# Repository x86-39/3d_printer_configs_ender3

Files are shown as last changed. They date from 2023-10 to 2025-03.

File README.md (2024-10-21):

# creality_ender3_sprite_pro_configs
Configurations for my Ender 3 with the Creality Sprite Pro extruder

It was bought as a stock Ender 3, and I've added the following upgrades:
- Creality Sprite Pro extruder
- BLTouch
- Dual Z-axis
- Raspberry Pi 4 with Moonsail
- Klipper firmware
- USB webcam

## Generate PrusaSlicer print configs

I still include these in the repo bcs having an easy history of changes is nice. But you can generate them yourself if you want to change the settings.

The print configs in the PrusaSlicer folder are generated from the `generate.yml` playbook. Why Ansible? Because it's my golden hammer, next question. It takes a base config in `roles/generate_print/templates/` and generates a config for each possible permutation of variables such as speed, toughness and precision. You can then use `./copy-to-prusaslicer.sh` to copy the generated configs to your PrusaSlicer config folder.
Is this the best way to do it? No definitely not, but it works for me and I'm stubborn as fuck and will use Ansible when I can.
```
ansible-playbook generate.yml
```

Also, the playbook is a mess. I definitely could've procedurally generated it, but I was tired and just wanted it to work and don't think anyone is gonna download these anyway!

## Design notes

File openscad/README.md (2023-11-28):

# Creality Sprite Pro 40mm Fan Duct
I broke my Sprite Pro hot end cooling fan, so I made a model so it fits a 40mm fan I had instead of a 30mm fan. I don't use this anymore since I have a new 30mm fan and board now, but it worked well for a while. Here's the model if anyone else needs it. I used heat inserts to fit the screws for the board, fan and BLTouch.

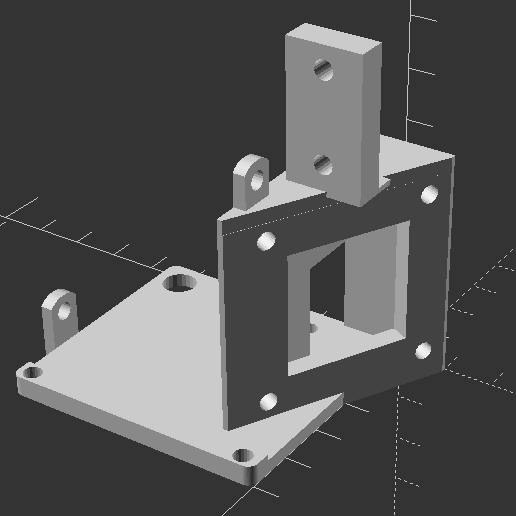
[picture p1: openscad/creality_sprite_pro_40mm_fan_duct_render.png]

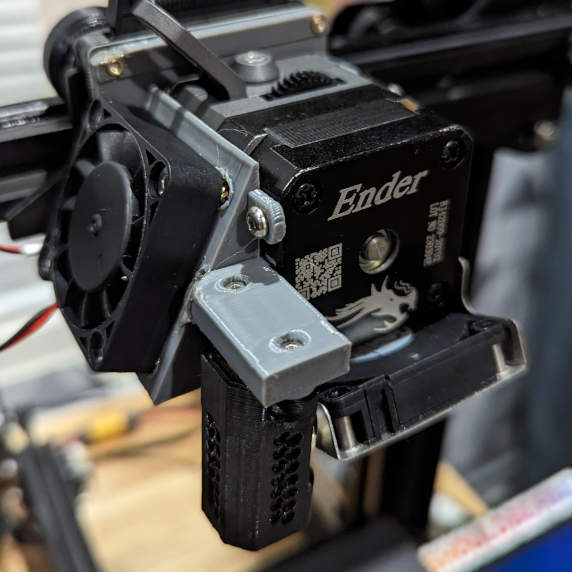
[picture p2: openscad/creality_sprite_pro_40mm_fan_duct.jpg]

<br clear="left"/>

You can download the model at the [Releases tab](https://github.com/diademiemi/3d_printer_configs_ender3/releases/tag/2023-10-28)

# Creality Sprite Pro BLTouch Raiser
The BLTouch I use was too low, it kept bumping into prints and especially the bed clips, so I made a model to raise it by 3.6 millimeters. This will offset the Z axis by 3.5 millimeters, X axis by 13.5 millimeters and Y axis by 0 millimeters.

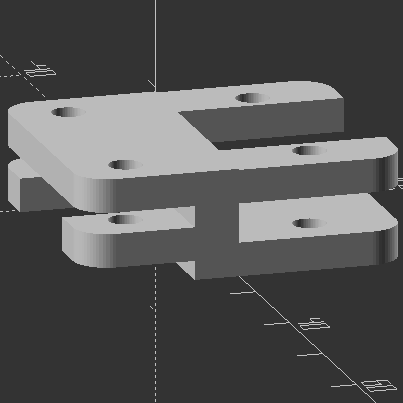
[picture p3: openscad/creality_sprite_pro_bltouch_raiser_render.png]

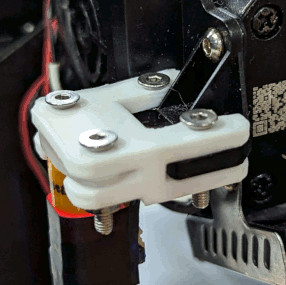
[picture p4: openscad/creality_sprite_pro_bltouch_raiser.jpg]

<br clear="left"/>

You can download the model at the [Releases tab](https://github.com/diademiemi/3d_printer_configs_ender3/releases/tag/2023-11-26)

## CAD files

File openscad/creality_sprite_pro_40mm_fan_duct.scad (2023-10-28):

/*
I broke my Sprite Pro hot end cooling fan, so I made a model so it fits a 40mm fan instead of a 30mm fan. I don't use this anymore since I have a new 30mm fan and board now, but it worked well for a while. Here's the model if anyone else needs it
*/
// github.com/diademiemi/openscad_common
include <openscad_common/rounded_figures.scad>

union() {

    // MAIN BODY

    difference() {
        union() {
            // Main body
            rounded_cube([54, 50.5, 2.8], 2, flat_minus_z = true, flat_plus_z = true);

            // Side screw plate
            difference() {
                // Plate
                translate([54, 31, 0]) {
                    rounded_cube([2.5, 7.1, 13], 4, flat_minus_z = true, flat_minus_x = true, flat_plus_x = true);
                }

                // Hole
                translate([54, 34.55, 9.5]) rotate([0,90,0]) {
                    cylinder(r = 1.8, h = 3, $fn=24);
                    
                }

            }

            // Top notch
            translate([0, 45.5, 2.8]) {
                rounded_cube([54, 5, 1.3], 2, flat_minus_z = true, flat_plus_z = true, flat_minus_y = true);
            }
        }

        // Top notch heat inserts, TOO FAR TO THE CENTER
        translate([0, 48, 0]) {
            translate([3.5, 0, 0]) {
                cylinder(r = 1.9, h = 5, $fn=24);
            }
            translate([51, 0, 0]) {
                cylinder(r = 1.9, h = 5, $fn=24);
            }
        }

        translate([11.25, 40 , 0]) {
            rounded_cube([30, 9.5, 1.8], 2);
        }

        // Square cutout
        translate([25, 0, 0]) {
            rounded_cube([12, 8, 3], 3, flat_minus_z = true, flat_plus_z = true, flat_minus_y = true);
        }

        // Screw
        translate([17.2, 5.6, 0]) {
            cylinder(r = 1.8, h = 3, $fn=24);
        }

        // Screw passthrough
        translate([48.5, 5.5, 0]) {
            cylinder(r = 3.5, h = 3, $fn=24);
        }

        // Cutout for heater pins
        translate([44, 10, 0]) {
            rounded_cube([10, 5, 2], 3, flat_minus_z = true, flat_plus_z = true, flat_plus_x = true);
        }
    }

    // FAN DUCT
    
    cube([3,3,2.8]); // Make corner flat
    // Don't cross into next part
    intersection() {
        translate([-10,0,0]) cube([22,42,45.6]);
        union() {
            translate([-9.5, 2, 2.8]) rotate([0,0,-27]) {
                difference() {
                    // Fan mount
                    translate([0,-5,0]) cube([4, 55, 40]);  // Actual size is not 50, but I use 55 so it fills in the corners of the intersection
                    // Fan hole
                    translate([0, 7.5, 7.5]) cube([4, 25, 25]);


                    // Screw holes
                    rotate([0,-90,0]) translate([3.4,3.4,-4]) cylinder(r=1.8, h=5, $fn=24);
                    rotate([0,-90,0]) translate([36.6,3.4,-4]) cylinder(r=1.8, h=5, $fn=24);
                    rotate([0,-90,0]) translate([3.4,36.6,-4]) cylinder(r=1.8, h=5, $fn=24);
                    rotate([0,-90,0]) translate([36.6,36.6,-4]) cylinder(r=1.8, h=5, $fn=24);

                }

            }
            // Bottom plate
            hull() {
                translate([-10, 0, 0]) cube([22, 1, 2.8]);
                translate([11, 0, 0]) rotate([0, 0, 0]) rounded_cube([2, 42, 2.8], 2, flat_minus_y = true, flat_plus_y = true);
            }
            // Top plate
            hull() {
                translate([-10, 0, 42.8]) cube([22, 1, 2.8]);
                translate([11, 0, 42.8]) rotate([0, 0, 0]) rounded_cube([2, 42, 2.8], 2, flat_minus_y = true, flat_plus_y = true);
            }
            // Front plate
            translate([-10, 0, 0]) cube([22, 1, 42.8]);

            // Closing plate
            translate([11, 0, 0]) difference() {
                cube([1, 40, 42.8]);
                // Vent hole
                translate([0, 0, 2.8]) cube([1, 15, 20]);
            }

        }

    }

    // BLTouch mount
    translate([-5, 18, 45.6]) difference(){
    
        cube([15, 6, 27]);

        translate([7.5,6,5]) rotate([90,0,0]) cylinder(r=1.9, h=6, $fn=24);
        translate([7.5,6,22.5]) rotate([90,0,0]) cylinder(r=1.9, h=6, $fn=24);


    }
    translate([-5,14,44.6]) cube([10,10,1]);

    translate([9.5, 30, 45.6]) difference() {
            // Side screw plate
            // Plate
            rounded_cube([2.5, 7.1, 8], 4, flat_minus_z = true, flat_minus_x = true, flat_plus_x = true);

            // Hole
            translate([0, 3.5, 4.25]) rotate([0,90,0]) {
                cylinder(r = 1.8, h = 3, $fn=24);
            }

        }

    /*
    The fan duct should close at the bottom. Have a panel at the side facing the extruder.
    It should only open at the panel at the bottom left for the size of the betal block.
    This is where the air exists. The duct can be moved 1cm to the right
    */


}

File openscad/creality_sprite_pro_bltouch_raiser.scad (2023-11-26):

include <openscad_common/rounded_figures.scad>

bltouch_size = [25, 10, 3];
extruder_size = [25, 15, 3];

screw_hole_radius = 1.5;


extra_height = 3.6;

wall_thickness = 4;
sprite_pro_extruder_thickness = 3.5;
wall_height = bltouch_size[2]*2 + extra_height;

bltouch_mount_thickness = 1.9;

module bltouch_mount(bltouch_size = bltouch_size, screw_hole_radius = screw_hole_radius) {
    difference() {
        rounded_cube(bltouch_size, 3, flat_plus_z=true, flat_minus_z=true, flat_minus_y=true);
        translate([2.5 + screw_hole_radius, bltouch_size[1] / 2, 0]) {
            translate([0, 0, bltouch_size[2]/2]) cylinder(r=1.5, h=bltouch_size[2]*2, center=true, $fn=64);
        }
        translate([bltouch_size[0] - 2.5 - screw_hole_radius, bltouch_size[1] / 2, 0]) {
            translate([0, 0, bltouch_size[2]/2]) cylinder(r=1.5, h=bltouch_size[2]*2, center=true, $fn=64);
        }
    }
}


module extruder_mount(extruder_size = extruder_size, screw_hole_radius = screw_hole_radius) {
    difference() {
        rounded_cube(extruder_size, 3, flat_plus_z=true, flat_minus_z=true, flat_minus_y=true);
        translate([2.5 + screw_hole_radius, extruder_size[1] / 2, 0]) {
            translate([0, 0, extruder_size[2]/2]) cylinder(r=1.5, h=extruder_size[2]*2, center=true, $fn=64);
        }
        translate([extruder_size[0] - 2.5 - screw_hole_radius, extruder_size[1] / 2, 0]) {
            translate([0, 0, extruder_size[2]/2]) cylinder(r=1.5, h=extruder_size[2]*2, center=true, $fn=64);
        }
    }
}


// Extruder Mount

extruder_mount();

translate([0, 0, bltouch_size[2] + sprite_pro_extruder_thickness]) {
    difference() {
        extruder_mount();
        translate([extruder_size[0]/4, 0, 0]) cube([extruder_size[0]/2, extruder_size[1], extruder_size[2]]);
    }
}

// Wall

translate([0, -wall_thickness, 0]) {
    cube([bltouch_size[0], wall_thickness, wall_height]);
}

// BlTouch Mount

translate([0, -(wall_thickness), (bltouch_size[2]*2) + extra_height]) {
    rotate([180, 0, 0]) bltouch_mount();
}

translate([0, -(wall_thickness), (bltouch_size[2]) + extra_height - bltouch_mount_thickness]) {
    rotate([180, 0, 0]) difference() {
        bltouch_mount();
        translate([bltouch_size[0]/4, 0, 0]) cube([bltouch_size[0]/2, bltouch_size[1], bltouch_size[2]]);
    }
}

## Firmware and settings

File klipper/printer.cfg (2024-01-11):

# This file contains pin mappings for the stock 2020 Creality Ender 3
# V2. To use this config, during "make menuconfig" select the
# STM32F103 with a "28KiB bootloader" and serial (on USART1 PA10/PA9)
# communication.

# If you prefer a direct serial connection, in "make menuconfig"
# select "Enable extra low-level configuration options" and select
# serial (on USART3 PB11/PB10), which is broken out on the 10 pin IDC
# cable used for the LCD module as follows:
# 3: Tx, 4: Rx, 9: GND, 10: VCC

# Flash this firmware by copying "out/klipper.bin" to a SD card and
# turning on the printer with the card inserted. The firmware
# filename must end in ".bin" and must not match the last filename
# that was flashed.

# See docs/Config_Reference.md for a description of parameters.

[include mainsail.cfg]

[include timelapse.cfg]

[stepper_x]
step_pin: PB9
dir_pin: PC2
enable_pin: !PC3
microsteps: 16
rotation_distance: 40
endstop_pin: ^PA5
position_endstop: -10
position_min: -15
position_max: 210
homing_speed: 75

[stepper_y]
step_pin: PB7
dir_pin: PB8
enable_pin: !PC3
microsteps: 16
rotation_distance: 40
endstop_pin: ^PA6
position_endstop: -10
position_min: -15
position_max: 220
homing_speed: 75

[stepper_z]
step_pin: PB5
dir_pin: !PB6
enable_pin: !PC3
microsteps: 16
rotation_distance: 8
endstop_pin: probe:z_virtual_endstop
#position_endstop: 0.0
position_min: -5
position_max: 250

[extruder]
max_extrude_only_distance: 100.0
step_pin: PB3
dir_pin: PB4
enable_pin: !PC3
microsteps: 16
#rotation_distance: 7.531  # Stock
rotation_distance: 7.55  # Calibrated
nozzle_diameter: 0.400
filament_diameter: 1.750
heater_pin: PA1
sensor_type: EPCOS 100K B57560G104F
sensor_pin: PC5
control: pid
# tuned for stock hardware with 200 degree Celsius target
pid_Kp: 24.488
pid_Ki: 1.020
pid_Kd: 146.928
min_temp: 0
max_temp: 270

[verify_heater extruder]
heating_gain: 1
hysteresis: 7
check_gain_time: 30
max_error: 150

[heater_bed]
heater_pin: PA2
sensor_type: EPCOS 100K B57560G104F
sensor_pin: PC4
control: pid
# tuned for stock hardware with 50 degree Celsius target
pid_Kp: 54.027
pid_Ki: 0.770
pid_Kd: 948.182
min_temp: 0
max_temp: 130

[fan]
pin: PA0
max_power: 1.0
cycle_time: 0.010

[mcu]
serial: /dev/serial/by-id/usb-1a86_USB_Serial-if00-port0
restart_method: command

[printer]
kinematics: cartesian
max_velocity: 300
max_accel: 3000
max_z_velocity: 5
max_z_accel: 100

[bltouch]
sensor_pin: ^PROBE_IN
control_pin: PROBE_OUT
x_offset: -41
y_offset: -43
#z_offset: 4.950
z_offset: 1.650
probe_with_touch_mode: true
stow_on_each_sample: true

[bed_mesh]
speed: 250
mesh_min: 5, 5
mesh_max: 165, 165
probe_count: 5,5
algorithm: bicubic
horizontal_move_z: 7

[safe_z_home]
home_xy_position: 137.5,127.5
speed: 75
z_hop: 15
z_hop_speed: 5

######################################################################
# 128x64 Full Graphic Creality CR10 / ENDER 3 stockdisplay
######################################################################

# This section is used for a Creality "12864" display with a single
# ribbon cable between the display's EXP3 plug and the
# micro-controller board's EXP1 connector.

[display]
lcd_type: st7920
cs_pin: EXP1_7
sclk_pin: EXP1_6
sid_pin: EXP1_8
encoder_pins: ^EXP1_5, ^EXP1_3
click_pin: ^!EXP1_2

[display_status]

[output_pin beeper]
pin: EXP1_1
value: 0
shutdown_value: 0
pwm: True
cycle_time: 0.0005 ; Default beeper tone in kHz. 1 / 0.0005 = 2000Hz (2kHz)

[board_pins]
aliases:
  EXP1_1=PC6,EXP1_3=PB10,EXP1_5=PB14,EXP1_7=PB12,EXP1_9=<GND>,
  EXP1_2=PB2,EXP1_4=PB11,EXP1_6=PB13,EXP1_8=PB15,EXP1_10=<5V>,
  PROBE_IN=PB1,PROBE_OUT=PB0,FIL_RUNOUT=PC6


[gcode_macro BEEP]
gcode:
    # Parameters
    {% set i = params.I|default(3)|int %}           ; Iterations (number of times to beep).
    {% set dur = params.DUR|default(500)|int %}     ; Duration/wait of each beep in ms. Default 100ms.
    {% set freq = params.FREQ|default(2500)|int %}  ; Frequency in Hz. Default 2kHz.

    {% for iteration in range(i|int) %}
        SET_PIN PIN=beeper VALUE=0.8 CYCLE_TIME={ 1.0/freq if freq > 0 else 1 }
        G4 P{dur}
        SET_PIN PIN=beeper VALUE=0
        G4 P{dur}
    {% endfor %}

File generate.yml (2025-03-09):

- name: Generate PrusaSlicer configs
  hosts: localhost
  vars:
    speed_safe:
      perimeter_speed: 60
      small_perimeter_speed: 50
      external_perimeter_speed: 60
      infill_speed: 75
      solid_infill_speed: 80
      top_solid_infill_speed: 75
      support_material_speed: 50
      support_material_interface_speed: 50
      bridge_speed: 30
      gap_fill_speed: 80
      ironing_speed: 50

      overhang_speed_0: 8
      overhang_speed_1: 15
      overhang_speed_2: 25
      overhang_speed_3: 40

      travel_speed: 80
      travel_speed_z: 5

      first_layer_speed: 20

      external_perimeter_acceleration: 500
      perimeter_acceleration: 600
      top_solid_infill_acceleration: 700
      solid_infill_acceleration: 800
      infill_acceleration: 700
      bridge_acceleration: 600
      first_layer_acceleration: 100
      travel_acceleration: 700
      default_acceleration: 700

      max_print_speed: 80
      max_volumetric_speed: 10
    speed_fast:
      perimeter_speed: 175
      small_perimeter_speed: 140
      external_perimeter_speed: 140
      infill_speed: 200
      solid_infill_speed: 150
      top_solid_infill_speed: 150
      support_material_speed: 75
      support_material_interface_speed: 80
      bridge_speed: 45
      gap_fill_speed: 120
      ironing_speed: 70

      overhang_speed_0: 10
      overhang_speed_1: 25
      overhang_speed_2: 40
      overhang_speed_3: 60

      travel_speed: 200
      travel_speed_z: 5

      first_layer_speed: 20

      external_perimeter_acceleration: 700
      perimeter_acceleration: 900
      top_solid_infill_acceleration: 700
      solid_infill_acceleration: 900
      infill_acceleration: 900
      bridge_acceleration: 800
      first_layer_acceleration: 500
      travel_acceleration: 1400
      default_acceleration: 1400

      max_print_speed: 180
      max_volumetric_speed: 15
    toughness_prototype:
      perimeters: 2
      bottom_solid_layers: 1
      top_solid_layers: 1
      fill_density: 7
      fill_pattern: rectilinear
    toughness_standard:
      perimeters: 3
      bottom_solid_layers: 3
      top_solid_layers: 3
      fill_density: 15
      fill_pattern: honeycomb
    toughness_thick_walls:
      perimeters: 5
      bottom_solid_layers: 4
      top_solid_layers: 4
      fill_density: 15
      fill_pattern: honeycomb
    toughness_strong:
      perimeters: 4
      bottom_solid_layers: 3
      top_solid_layers: 3
      fill_density: 30
      fill_pattern: honeycomb
    toughness_solid:
      perimeters: 5
      bottom_solid_layers: 5
      top_solid_layers: 5
      fill_density: 70
      fill_pattern: honeycomb
    precision_fine:
      layer_height: 0.12
      first_layer_height: 0.2
    precision_detailed:
      layer_height: 0.2
      first_layer_height: 0.25
    precision_standard:
      layer_height: 0.25
      first_layer_height: 0.28
    precision_chunky:
      layer_height: 0.32
      first_layer_height: 0.32

  roles:
  # Fine: 0
  # Detailed: 1
  # Standard: 2
  # Chunky: 3

  # Prototype: 0
  # Standard: 1
  # Thick walls: 2
  # Strong: 3
  # Solid: 4

  # Safe: 0
  # Fast: 1

  # Fine - Prototype
    - { role: generate_print, filename: "Creality Ender 3 Custom - [000] P:Fine, T:Prototype, S:Safe",
        precision: "{{ precision_fine }}", toughness: "{{ toughness_prototype }}", speed: "{{ speed_safe }}" }
    - { role: generate_print, filename: "Creality Ender 3 Custom - [001] P:Fine, T:Prototype, S:Fast",
        precision: "{{ precision_fine }}", toughness: "{{ toughness_prototype }}", speed: "{{ speed_fast }}" }

  # Fine - Standard
    - { role: generate_print, filename: "Creality Ender 3 Custom - [010] P:Fine, T:Standard, S:Safe",
        precision: "{{ precision_fine }}", toughness: "{{ toughness_standard }}", speed: "{{ speed_safe }}" }
    - { role: generate_print, filename: "Creality Ender 3 Custom - [011] P:Fine, T:Standard, S:Fast",
        precision: "{{ precision_fine }}", toughness: "{{ toughness_standard }}", speed: "{{ speed_fast }}" }

  # Fine - Thick walls
    - { role: generate_print, filename: "Creality Ender 3 Custom - [020] P:Fine, T:Thick walls, S:Safe",
        precision: "{{ precision_fine }}", toughness: "{{ toughness_thick_walls }}", speed: "{{ speed_safe }}" }
    - { role: generate_print, filename: "Creality Ender 3 Custom - [021] P:Fine, T:Thick walls, S:Fast",
        precision: "{{ precision_fine }}", toughness: "{{ toughness_thick_walls }}", speed: "{{ speed_fast }}" }

  # Fine - Strong
    - { role: generate_print, filename: "Creality Ender 3 Custom - [030] P:Fine, T:Strong, S:Safe",
        precision: "{{ precision_fine }}", toughness: "{{ toughness_strong }}", speed: "{{ speed_safe }}" }
    - { role: generate_print, filename: "Creality Ender 3 Custom - [031] P:Fine, T:Strong, S:Fast",
        precision: "{{ precision_fine }}", toughness: "{{ toughness_strong }}", speed: "{{ speed_fast }}" }
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

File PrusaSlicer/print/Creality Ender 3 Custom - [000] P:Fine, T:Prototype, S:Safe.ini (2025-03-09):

arc_fitting = disabled
avoid_crossing_curled_overhangs = 0
avoid_crossing_perimeters = 0
avoid_crossing_perimeters_max_detour = 0
bottom_fill_pattern = monotonic
bottom_solid_layers = 1
bottom_solid_min_thickness = 0
bridge_acceleration = 600
bridge_angle = 0
bridge_flow_ratio = 0.98
bridge_speed = 30
brim_separation = 0
brim_type = outer_only
brim_width = 0
compatible_printers = "Creality Ender 3 Custom";"Creality Ender 3 Custom (Unsafe)"
compatible_printers_condition = 
complete_objects = 1
default_acceleration = 700
dont_support_bridges = 1
draft_shield = disabled
elefant_foot_compensation = 0.01
enable_dynamic_overhang_speeds = 1
external_perimeter_acceleration = 500
external_perimeter_extrusion_width = 0.42
external_perimeter_speed = 60
external_perimeters_first = 0
extra_perimeters = 1
extra_perimeters_on_overhangs = 1
extruder_clearance_height = 60
extruder_clearance_radius = 35
extrusion_width = 0.45
fill_angle = 45
fill_density = 7%
fill_pattern = rectilinear
first_layer_acceleration = 100
first_layer_acceleration_over_raft = 0
first_layer_extrusion_width = 0.45
first_layer_height = 0.2
first_layer_speed = 20
first_layer_speed_over_raft = 30
fuzzy_skin = none
fuzzy_skin_point_dist = 0.8
fuzzy_skin_thickness = 0.3
gap_fill_enabled = 1
gap_fill_speed = 80
gcode_binary = 0
gcode_comments = 0
gcode_label_objects = octoprint
gcode_resolution = 0.0125
gcode_substitutions = 
infill_acceleration = 700
infill_anchor = 600%
infill_anchor_max = 50
infill_every_layers = 1
infill_extruder = 1
infill_extrusion_width = 0.45
infill_first = 0
infill_overlap = 25%
infill_speed = 75
inherits = 
interface_shells = 0
ironing = 0
ironing_flowrate = 35%
ironing_spacing = 0.15
ironing_speed = 50
ironing_type = topmost
layer_height = 0.12
max_print_speed = 80
max_volumetric_extrusion_rate_slope_negative = 0
max_volumetric_extrusion_rate_slope_positive = 0
max_volumetric_speed = 10
min_bead_width = 85%
min_feature_size = 25%
min_skirt_length = 0
mmu_segmented_region_interlocking_depth = 0
mmu_segmented_region_max_width = 0
notes = 
only_retract_when_crossing_perimeters = 0
ooze_prevention = 0
output_filename_format = [input_filename_base]-[year]-[month]-[day]T[hour]-[minute].gcode
overhang_speed_0 = 8%
overhang_speed_1 = 15%
overhang_speed_2 = 25%
overhang_speed_3 = 40%
overhangs = 1
perimeter_acceleration = 600
perimeter_extruder = 1
perimeter_extrusion_width = 0.4
perimeter_generator = arachne
perimeter_speed = 60
perimeters = 2
post_process = 
print_settings_id = Creality Ender 3 Custom - [210] P:Standard, T:Standard, S:Safe
raft_contact_distance = 0.1
raft_expansion = 1.5
raft_first_layer_density = 90%
raft_first_layer_expansion = 3
raft_layers = 0
resolution = 0
seam_position = aligned
single_extruder_multi_material_priming = 1
skirt_distance = 7
skirt_height = 1
skirts = 3
slice_closing_radius = 0.049
slicing_mode = regular
small_perimeter_speed = 50
solid_infill_acceleration = 800
solid_infill_below_area = 10
solid_infill_every_layers = 0
solid_infill_extruder = 1
solid_infill_extrusion_width = 0.45
solid_infill_speed = 80
spiral_vase = 0
staggered_inner_seams = 0
standby_temperature_delta = -5
support_material = 1
support_material_angle = 0
support_material_auto = 0
support_material_bottom_contact_distance = 0
support_material_bottom_interface_layers = -1
support_material_buildplate_only = 1
support_material_closing_radius = 2
support_material_contact_distance = 0.25
support_material_enforce_layers = 0
support_material_extruder = 1
support_material_extrusion_width = 0.35
support_material_interface_contact_loops = 0
support_material_interface_extruder = 1
support_material_interface_layers = 2
support_material_interface_pattern = rectilinear
support_material_interface_spacing = 0.5
support_material_interface_speed = 50
support_material_pattern = rectilinear
support_material_spacing = 4
support_material_speed = 50
support_material_style = organic
support_material_synchronize_layers = 0
support_material_threshold = 0
support_material_with_sheath = 1
support_material_xy_spacing = 0.5
support_tree_angle = 40
support_tree_angle_slow = 25
support_tree_branch_diameter = 2
support_tree_branch_diameter_angle = 5
support_tree_branch_diameter_double_wall = 3
support_tree_branch_distance = 1
support_tree_tip_diameter = 0.8
support_tree_top_rate = 15%
thick_bridges = 1
thin_walls = 1
top_fill_pattern = monotonic
top_infill_extrusion_width = 0.42
top_solid_infill_acceleration = 700
top_solid_infill_speed = 75
top_solid_layers = 1
top_solid_min_thickness = 0
travel_acceleration = 700
travel_speed = 80
travel_speed_z = 5
wall_distribution_count = 1
wall_transition_angle = 10
wall_transition_filter_deviation = 25%
wall_transition_length = 100%
wipe_tower = 0
wipe_tower_bridging = 10
wipe_tower_brim_width = 2
wipe_tower_cone_angle = 0
wipe_tower_extra_spacing = 100%
wipe_tower_extruder = 0
wipe_tower_no_sparse_layers = 0
wipe_tower_rotation_angle = 0
wipe_tower_width = 60
wipe_tower_x = 180
wipe_tower_y = 140
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

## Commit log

2023-10-14 Add configs
    [moonsail.cfg, printer.cfg, timelapse.cfg]
2023-10-14 Remove RO files
    [moonsail.cfg, timelapse.cfg]
2023-10-28 Add 40mm fan duct
    [creality_sprite_pro_40mm_fan_duct.scad]
2023-11-26 Config update 2023-11-26
    [printer.cfg]
2023-11-26 Add BLTouch raiser
    [creality_sprite_pro_bltouch_raiser.scad]
